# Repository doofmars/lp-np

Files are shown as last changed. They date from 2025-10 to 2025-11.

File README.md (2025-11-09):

lp-np
=====

The Low Profile - Numpad (lp-np) is my first attempt at creating my own PCB from scratch.
This was done with the long-lasting wish to create some hardware.
A keyboard (numpad in this case) is a first project with less complexity on the used parts and hardware.
In the past I gathered some experience in ordering and soldering a [Corne](https://github.com/foostan/crkbd) keyboard
and for creating this project I used the KiCad files as a template.
This helped me to get the right schematic and after some trial and error a layout that looks right.

**2025-11-09**: Assembly done

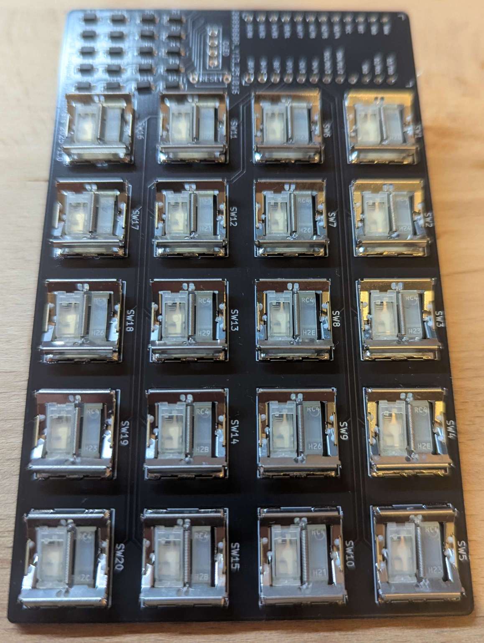
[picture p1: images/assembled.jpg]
assembled
 

**2025-10-28**: PCB has arrived

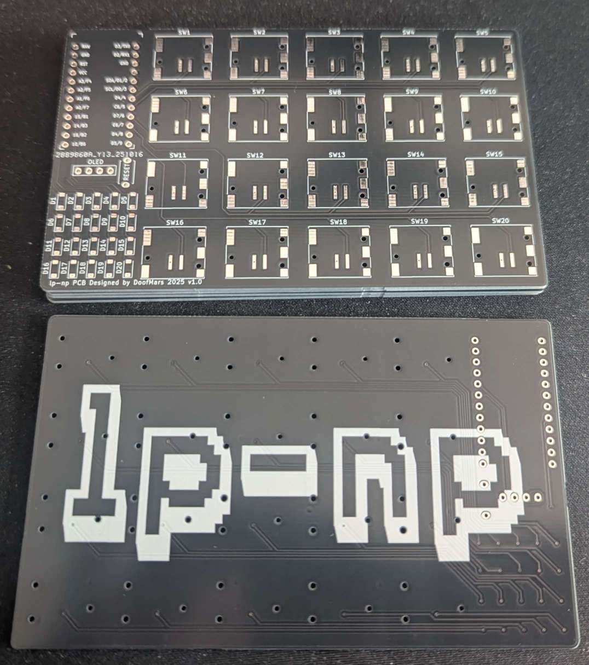
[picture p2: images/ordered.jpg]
ordered
 

**2025-10-15**: PCB is done next order all required parts and 3d-printing.

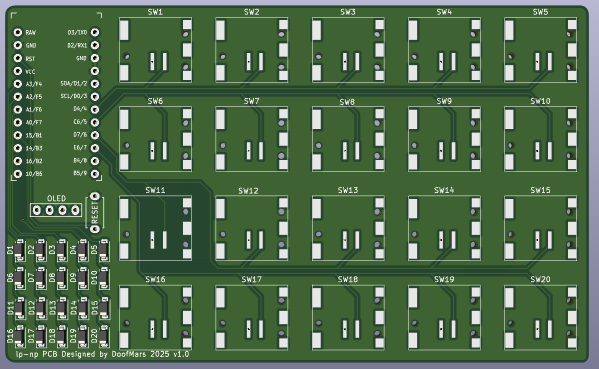
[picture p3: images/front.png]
front


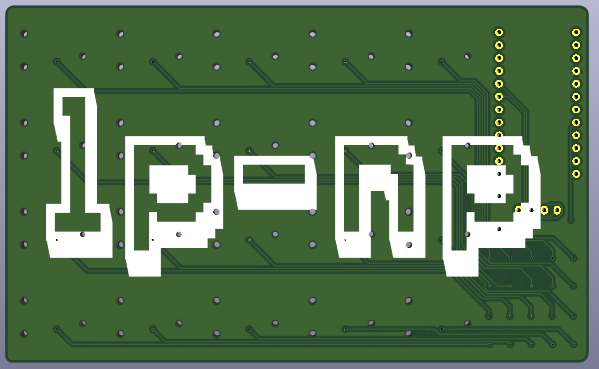
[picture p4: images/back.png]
back


## Parts and PCB footprint

The PCB design would not been possible without the aid of the [Corne](https://github.com/foostan/crkbd) keyboard project
where the base footprint for the used ProMicro and display header originate from.
For the switches I got my hands on the Cherry MX ULP (Ultra Low Profile) Switches which
are pretty well documented in [the repo of pashutk](https://github.com/pashutk/Cherry_MX_ULP/tree/main).
Here example projects, footprints, datasheets and sourcing information can be found.

## Caps

For the caps, I resorted to 3D printing my own.
A base model can be found in the [zmk-config-mikefive repo of mikeholscher](https://github.com/mikeholscher/zmk-config-mikefive/).
This repo uses _Kailh PG1316S_ switches, which have a similar footprint to Cherry switches.
Keycap.step files for 3D printing can be found in the repository.

# Bill of Materials (BOM)

| Reference | Component Description | Value | Amount |
|:---|:---|:---|:---|
| U | ProMicro (or compatible derivate) | | 1 |
| U-Header  | Generic connector, single row, | Conn_01x12 | 2 |
| J | Generic connector, single row, 01x04 | Conn_01x04 | 1 |
| RSW1 | Momentary Tact Tactile Push Button Switch 2 Pin DIP | 3x6 | 1 |
| OLED | Mini 0.91 Inch 128x32 OLED | Optional | 1 |
| D | Diode (SOD-123) | D | 20 |
| SW | Cherry MX ULP (Ultra Low Profile) Switches | SW_Push | 20 |

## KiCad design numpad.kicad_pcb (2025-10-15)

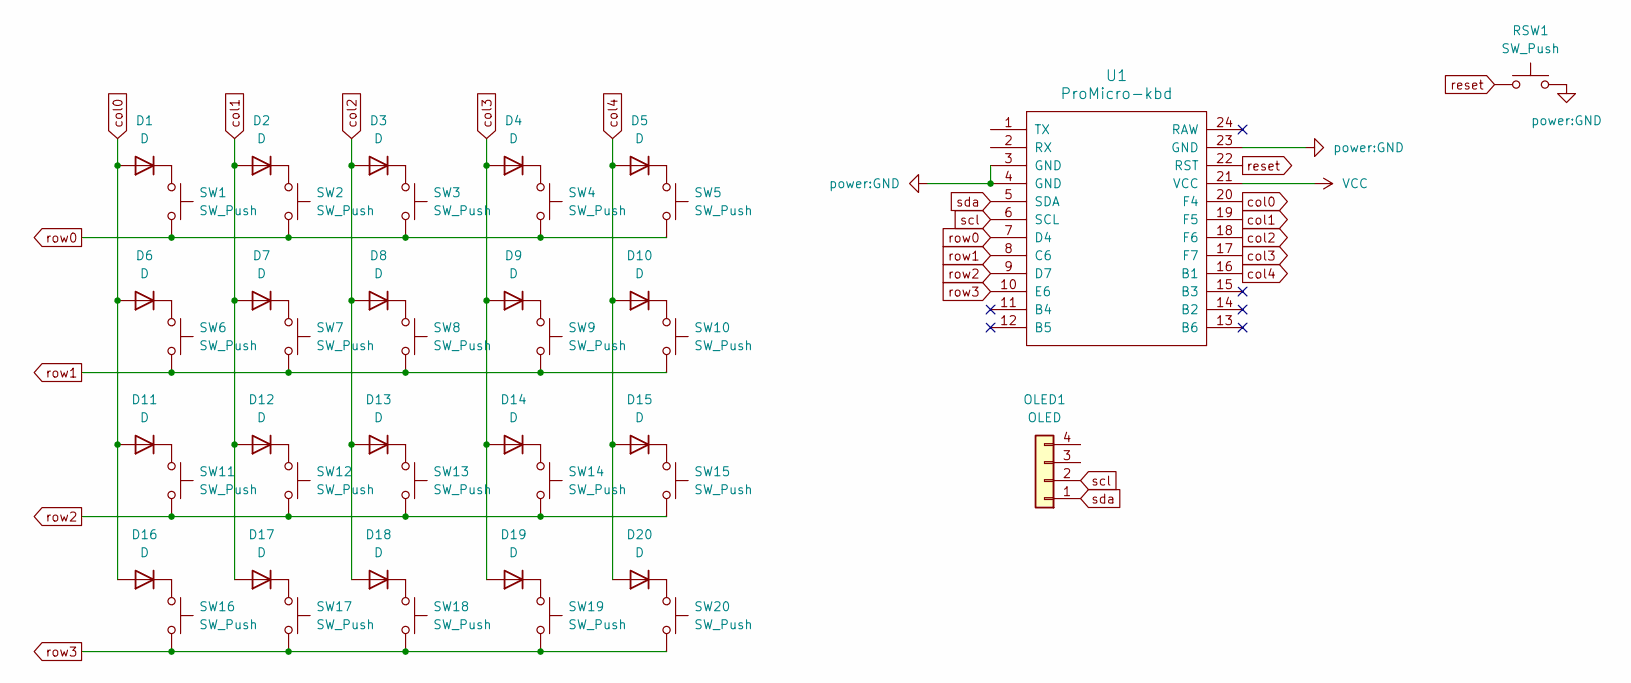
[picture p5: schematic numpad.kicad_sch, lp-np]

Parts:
D1, D2, D3, D4, D5, D6, D7, D8, D9, D10, D11, D12, D13, D14, D15, D16, D17, D18, D19, D20: D; D_SOD-123
OLED1: OLED; OLED_generic
RSW1: SW_Push; Reset
SW1, SW2, SW3, SW4, SW5, SW6, SW7, SW8, SW9, SW10, SW11, SW12, SW13, SW14, SW15, SW16, SW17, SW18, SW19, SW20: SW_Push; Cherry_ULP_SMD
U1: ProMicro-kbd; ProMikcro

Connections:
GND: RSW1.2, U1.3 (GND), U1.4 (GND), U1.23 (GND); also elsewhere on the board
LED: U1.1 (TX)
unnamed: D1.1 (K), SW1.1
unnamed: D2.1 (K), SW2.1
unnamed: D3.1 (K), SW3.1
unnamed: D4.1 (K), SW4.1
unnamed: D5.1 (K), SW5.1
unnamed: D6.1 (K), SW6.1
unnamed: D7.1 (K), SW7.1
unnamed: D8.1 (K), SW8.1
unnamed: D9.1 (K), SW9.1
unnamed: D10.1 (K), SW10.1
unnamed: D11.1 (K), SW11.1
unnamed: D12.1 (K), SW12.1
unnamed: D13.1 (K), SW13.1
unnamed: D14.1 (K), SW14.1
unnamed: D15.1 (K), SW15.1
unnamed: D16.1 (K), SW16.1
unnamed: D17.1 (K), SW17.1
unnamed: D18.1 (K), SW18.1
unnamed: D19.1 (K), SW19.1
unnamed: D20.1 (K), SW20.1
SCL: OLED1.2, U1.6 (SCL); also elsewhere on the board
SDA: OLED1.1, U1.5 (SDA); also elsewhere on the board
VCC: U1.21 (VCC); also elsewhere on the board
col0: D1.2 (A), D6.2 (A), D11.2 (A), D16.2 (A), U1.20 (F4)
col1: D2.2 (A), D7.2 (A), D12.2 (A), D17.2 (A), U1.19 (F5)
col2: D3.2 (A), D8.2 (A), D13.2 (A), D18.2 (A), U1.18 (F6)
col3: D4.2 (A), D9.2 (A), D14.2 (A), D19.2 (A), U1.17 (F7)
col4: D5.2 (A), D10.2 (A), D15.2 (A), D20.2 (A), U1.16 (B1)
col5: U1.15 (B3)
data: U1.2 (RX)
reset: RSW1.1, U1.22 (RST)
row0: SW1.2, SW2.2, SW3.2, SW4.2, SW5.2, U1.7 (D4)
row1: SW6.2, SW7.2, SW8.2, SW9.2, SW10.2, U1.8 (C6)
row2: SW11.2, SW12.2, SW13.2, SW14.2, SW15.2, U1.9 (D7)
row3: SW16.2, SW17.2, SW18.2, SW19.2, SW20.2, U1.10 (E6)

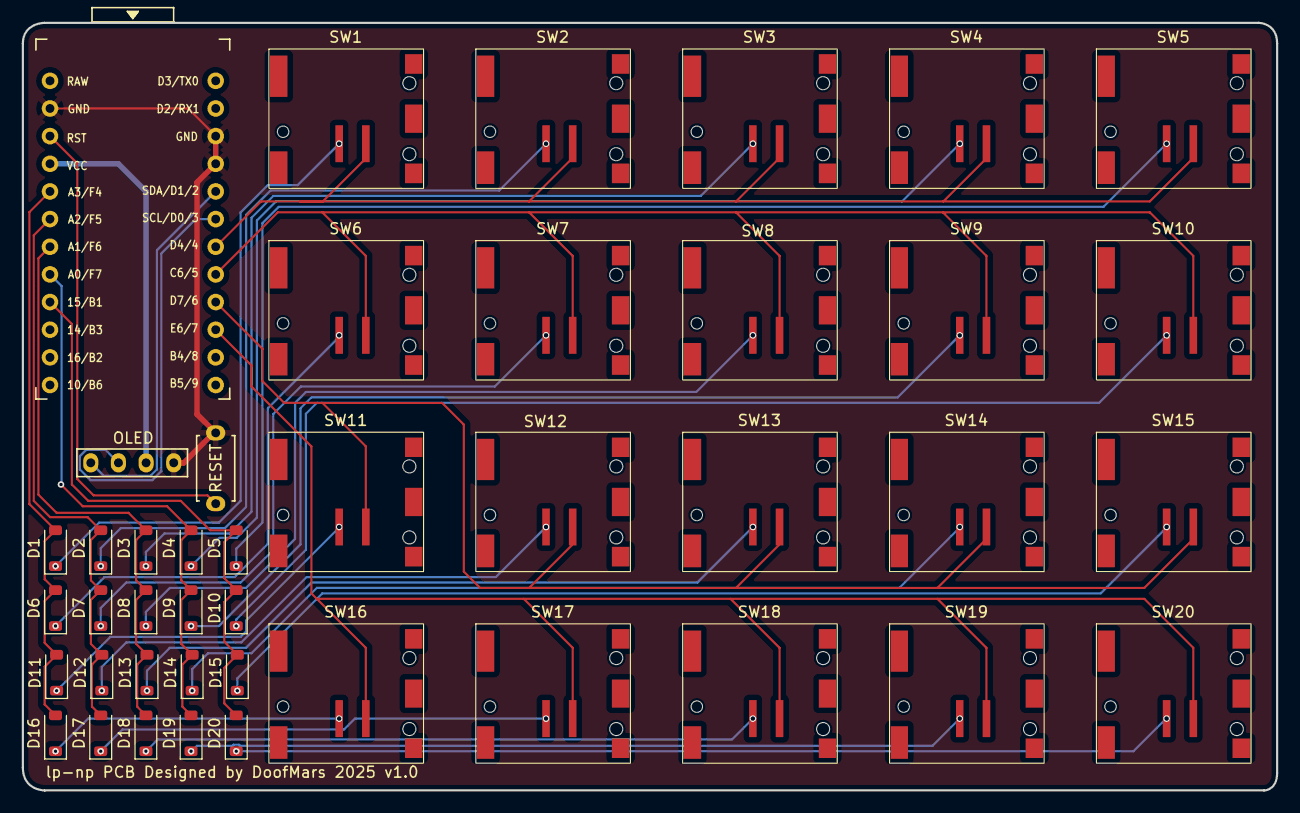
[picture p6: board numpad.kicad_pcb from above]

Board: 2 copper layers, 115.2 x 70.5 mm, 43 parts (0 on the bottom side), 34 nets.

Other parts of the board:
OLED: OLED; OLED_1side

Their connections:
GND: OLED.4; also elsewhere on the board
SCL: OLED.2; also elsewhere on the board
SDA: OLED.1; also elsewhere on the board
VCC: OLED.3; also elsewhere on the board
